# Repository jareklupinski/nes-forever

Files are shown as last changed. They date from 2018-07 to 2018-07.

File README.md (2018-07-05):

# nes-forever
A Raspberry Pi Hat for controlling the NES sound hardware directly

A work in progress of a circuit that keeps an NES chip in an infinite loop, constantly playing any note data that is shifted into the input registers.

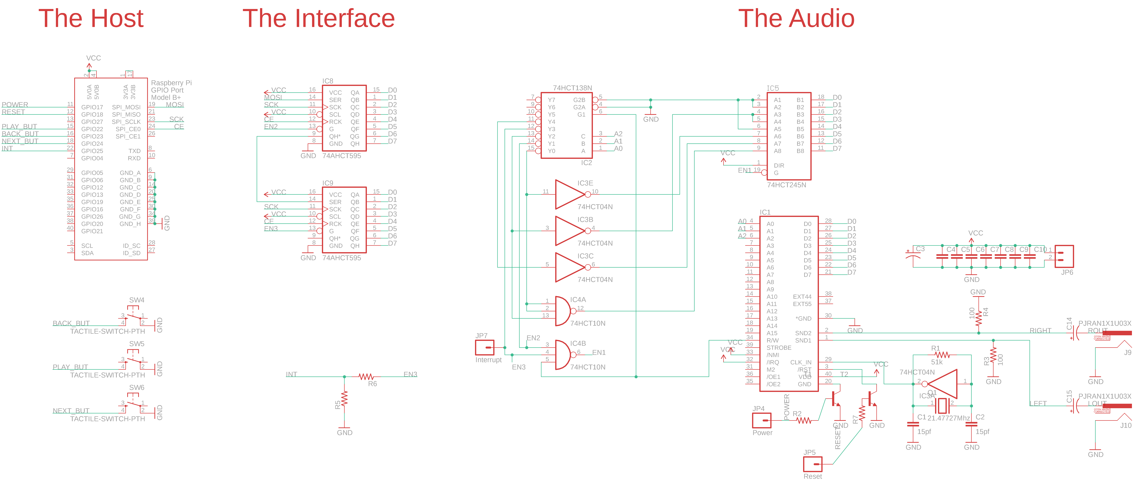
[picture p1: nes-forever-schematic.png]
schematic

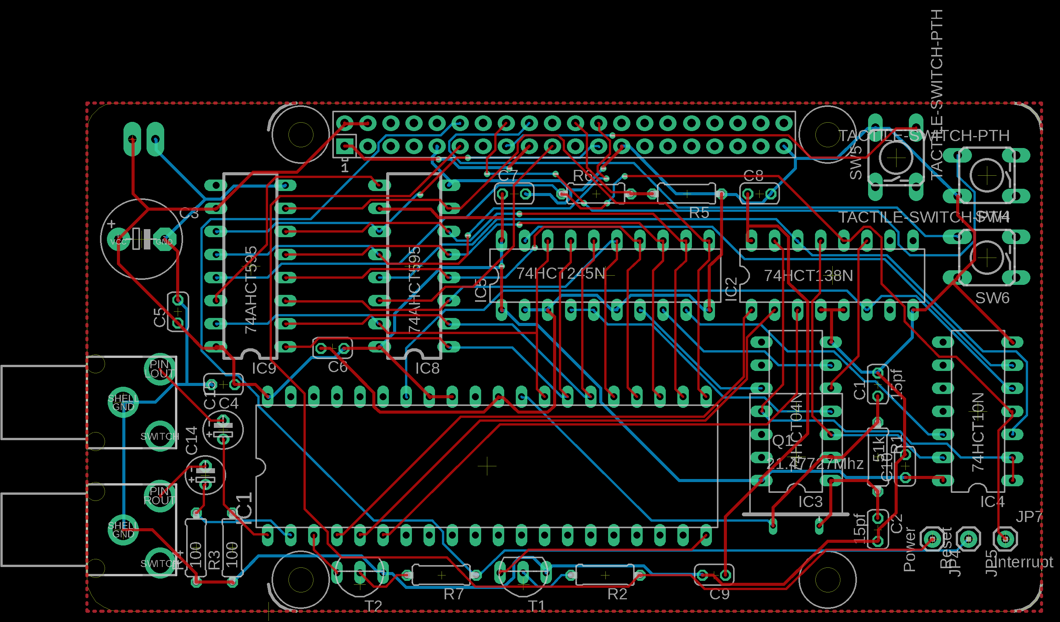
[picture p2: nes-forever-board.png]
board


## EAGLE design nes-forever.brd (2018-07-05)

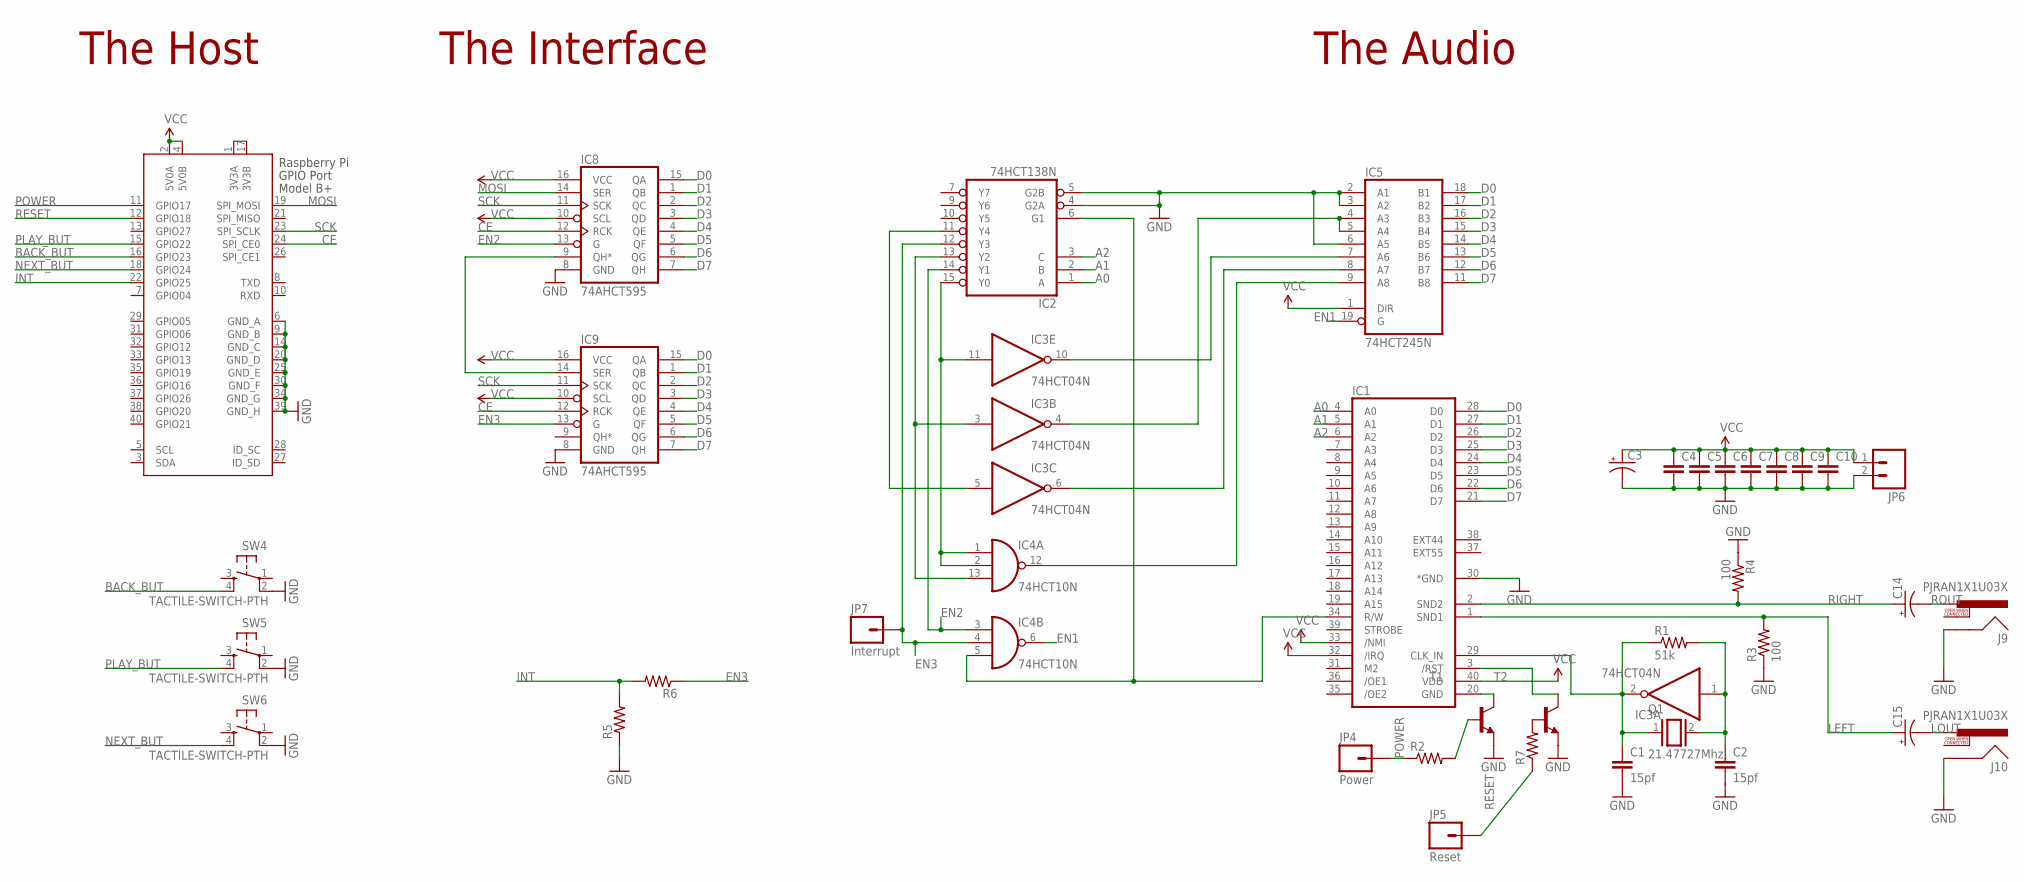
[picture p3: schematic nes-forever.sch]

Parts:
C1, C2: 15pf; C025-024X044
C3: CPOL-USE5-8.5; E5-8,5
C4, C5, C6, C7, C8, C9, C10: C-EU025-024X044; C025-024X044
C14, C15: CPOL-USE2-4; E2-4
IC1: 2A03; DIL40
IC2: 74HCT138N; DIL16
IC3: 74HCT04N; DIL14
IC4: 74HCT10N; DIL14
IC5: 74HCT245N; DIL20
IC8, IC9: 74AHCT595; DIL16
J9, J10: PJRAN1X1U03X; RCA
JP4: Power; 1X01
JP5: Reset; 1X01
JP6: M02; 1X02_LONGPADS
JP7: Interrupt; 1X01
Q1: 21.47727Mhz; Q
R1: 51k; 0207/7
R2, R5, R6, R7: R-US_0207/7; 0207/7
R3, R4: 100; 0207/7
SW4, SW5, SW6: TACTILE-SWITCH-PTH; TAC-SWITCH-PTH
T1, T2: 2N2222-NPN-TO92-EBC; TO92-EBC
X2: RASPI_BOARD_B+#_E4; RASPI_BOARD_B+_EDGES_4DRILL

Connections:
3.3V: X2.1 (3V3A), X2.17 (3V3B)
A0: IC1.4 (A0), IC2.1 (A)
A1: IC1.5 (A1), IC2.2 (B)
A2: IC1.6 (A2), IC2.3 (C)
A3: IC3.4 (O), IC5.4 (A3), IC5.5 (A4)
BACK_BUT: SW4.4, X2.16 (GPIO23)
CE: IC8.12 (RCK), IC9.12 (RCK), X2.24 (SPI_CE0)
D0: IC1.28 (D0), IC5.18 (B1), IC8.15 (QA), IC9.15 (QA)
D1: IC1.27 (D1), IC5.17 (B2), IC8.1 (QB), IC9.1 (QB)
D2: IC1.26 (D2), IC5.16 (B3), IC8.2 (QC), IC9.2 (QC)
D3: IC1.25 (D3), IC5.15 (B4), IC8.3 (QD), IC9.3 (QD)
D4: IC1.24 (D4), IC5.14 (B5), IC8.4 (QE), IC9.4 (QE)
D5: IC1.23 (D5), IC5.13 (B6), IC8.5 (QF), IC9.5 (QF)
D6: IC1.22 (D6), IC5.12 (B7), IC8.6 (QG), IC9.6 (QG)
D7: IC1.21 (D7), IC5.11 (B8), IC8.7 (QH), IC9.7 (QH)
EN1: IC4.6 (O), IC5.19 (G)
EN2: IC2.14 (Y1), IC4.3 (I0), IC8.13 (G)
EN3: IC2.12 (Y3), IC4.4 (I1), IC9.13 (G), JP7.1, R6.1
GND: C1.2, C2.2, C3.-, C4.2, C5.2, C6.2, C7.2, C8.2, C9.2, C10.2, IC1.30 (*GND), IC2.4 (G2A), IC2.5 (G2B), IC2.8 (GND), IC3.7 (GND), IC4.7 (GND), IC5.2 (A1), IC5.3 (A2), IC5.6 (A5), IC5.10 (GND), IC8.8 (GND), IC9.8 (GND), J9.SHELL, J10.SHELL, JP6.2, R3.1, R4.1, R5.1, SW4.2, SW5.2, SW6.2, T1.E, T2.E, X2.6 (GND_A), X2.9 (GND_B), X2.14 (GND_C), X2.20 (GND_D), X2.25 (GND_E), X2.30 (GND_F), X2.34 (GND_G), X2.39 (GND_H)
INT: R5.2, R6.2, X2.22 (GPIO25)
LEFT: C15.+, IC1.1 (SND1), R3.2
LOUT: C15.-, J10.PIN
MOSI: IC8.14 (SER), X2.19 (SPI_MOSI)
unnamed: IC3.10 (O), IC5.7 (A6)
unnamed: R7.2, T2.B
unnamed: IC3.6 (O), IC5.8 (A7)
unnamed: IC2.15 (Y0), IC3.11 (I), IC4.1 (I0), IC4.2 (I1)
unnamed: IC4.12 (O), IC5.9 (A8)
unnamed: IC2.13 (Y2), IC3.3 (I), IC4.13 (I2)
unnamed: IC2.11 (Y4), IC3.5 (I)
unnamed: IC1.34 (R/W), IC2.6 (G1), IC4.5 (I2)
unnamed: IC1.20 (GND), T1.C
unnamed: R2.2, T1.B
unnamed: C1.1, IC1.29 (CLK_IN), IC3.2 (O), Q1.1, R1.1
unnamed: C2.1, IC3.1 (I), Q1.2, R1.2
unnamed: IC1.3 (/RST), T2.C
unnamed: IC8.9 (QH*), IC9.14 (SER)
NEXT_BUT: SW6.4, X2.18 (GPIO24)
PLAY_BUT: SW5.4, X2.15 (GPIO22)
POWER: JP4.1, R2.1, X2.11 (GPIO17)
RESET: JP5.1, R7.1, X2.12 (GPIO18)
RIGHT: C14.+, IC1.2 (SND2), R4.2
ROUT: C14.-, J9.PIN
SCK: IC8.11 (SCK), IC9.11 (SCK), X2.23 (SPI_SCLK)
VCC: C3.+, C4.1, C5.1, C6.1, C7.1, C8.1, C9.1, C10.1, IC1.32 (/IRQ), IC1.33 (/NMI), IC1.40 (VDD), IC2.16 (VCC), IC3.14 (VCC), IC4.14 (VCC), IC5.1 (DIR), IC5.20 (VCC), IC8.10 (SCL), IC8.16 (VCC), IC9.10 (SCL), IC9.16 (VCC), JP6.1, X2.2 (5V0A), X2.4 (5V0B)

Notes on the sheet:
The Host
The Interface
The Audio

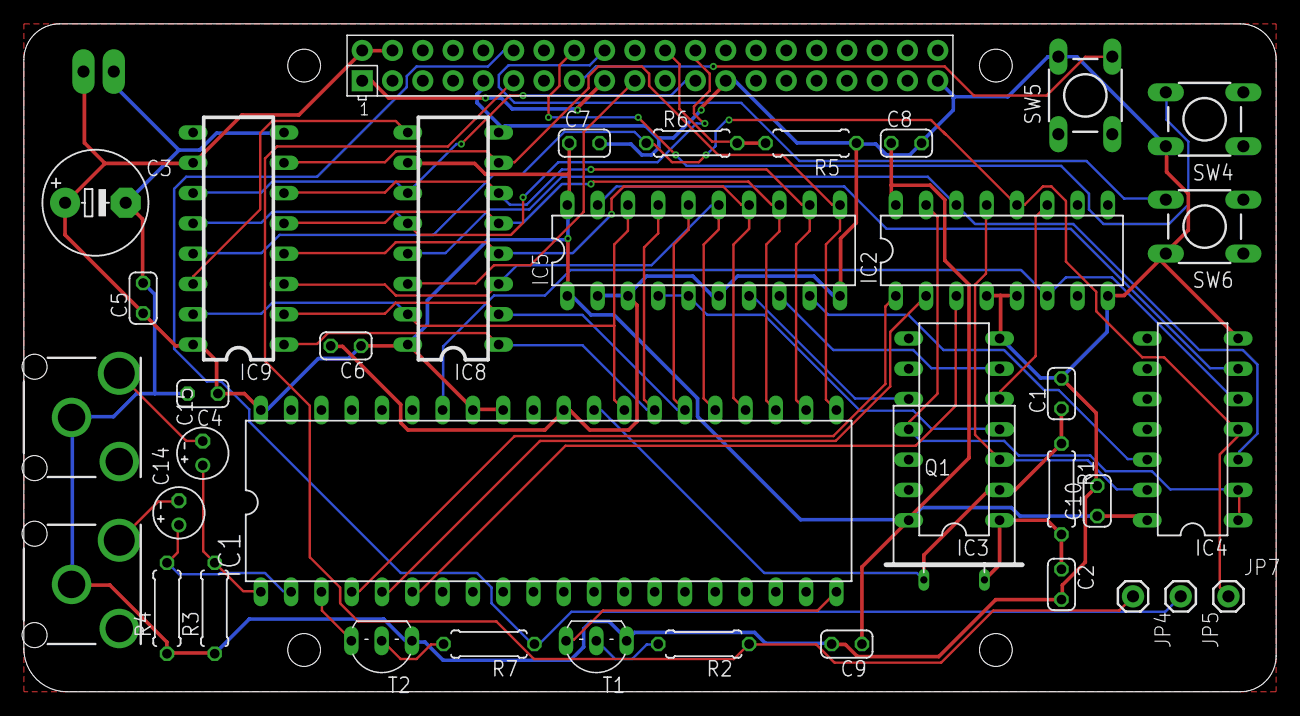
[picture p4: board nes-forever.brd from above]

Board: 2 copper layers, 105.0 x 56.0 mm, 39 parts (0 on the bottom side), 45 nets.

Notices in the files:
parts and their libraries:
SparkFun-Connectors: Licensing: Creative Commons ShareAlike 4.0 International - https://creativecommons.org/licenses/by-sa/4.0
